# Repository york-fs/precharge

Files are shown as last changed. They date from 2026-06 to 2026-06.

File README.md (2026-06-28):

# Precharge Board







The precharge board is responsible for precharging the inverter's large capacitance through a dedicated relay and
resistor before the AIRs close.

[Latest Release](https://github.com/york-fs/precharge/releases/latest)
[Interactive BOM](https://york-fs.github.io/precharge/ibom.html)

## Features

* **CAN Communication**
* **AIR Relay Control**
* **HV Sampling of Accumulator and TS sides**

Render Preview

## Cloning

A recursive clone must be used to download the `kicad-library` repository:

    git clone --recursive https://github.com/york-fs/precharge.git

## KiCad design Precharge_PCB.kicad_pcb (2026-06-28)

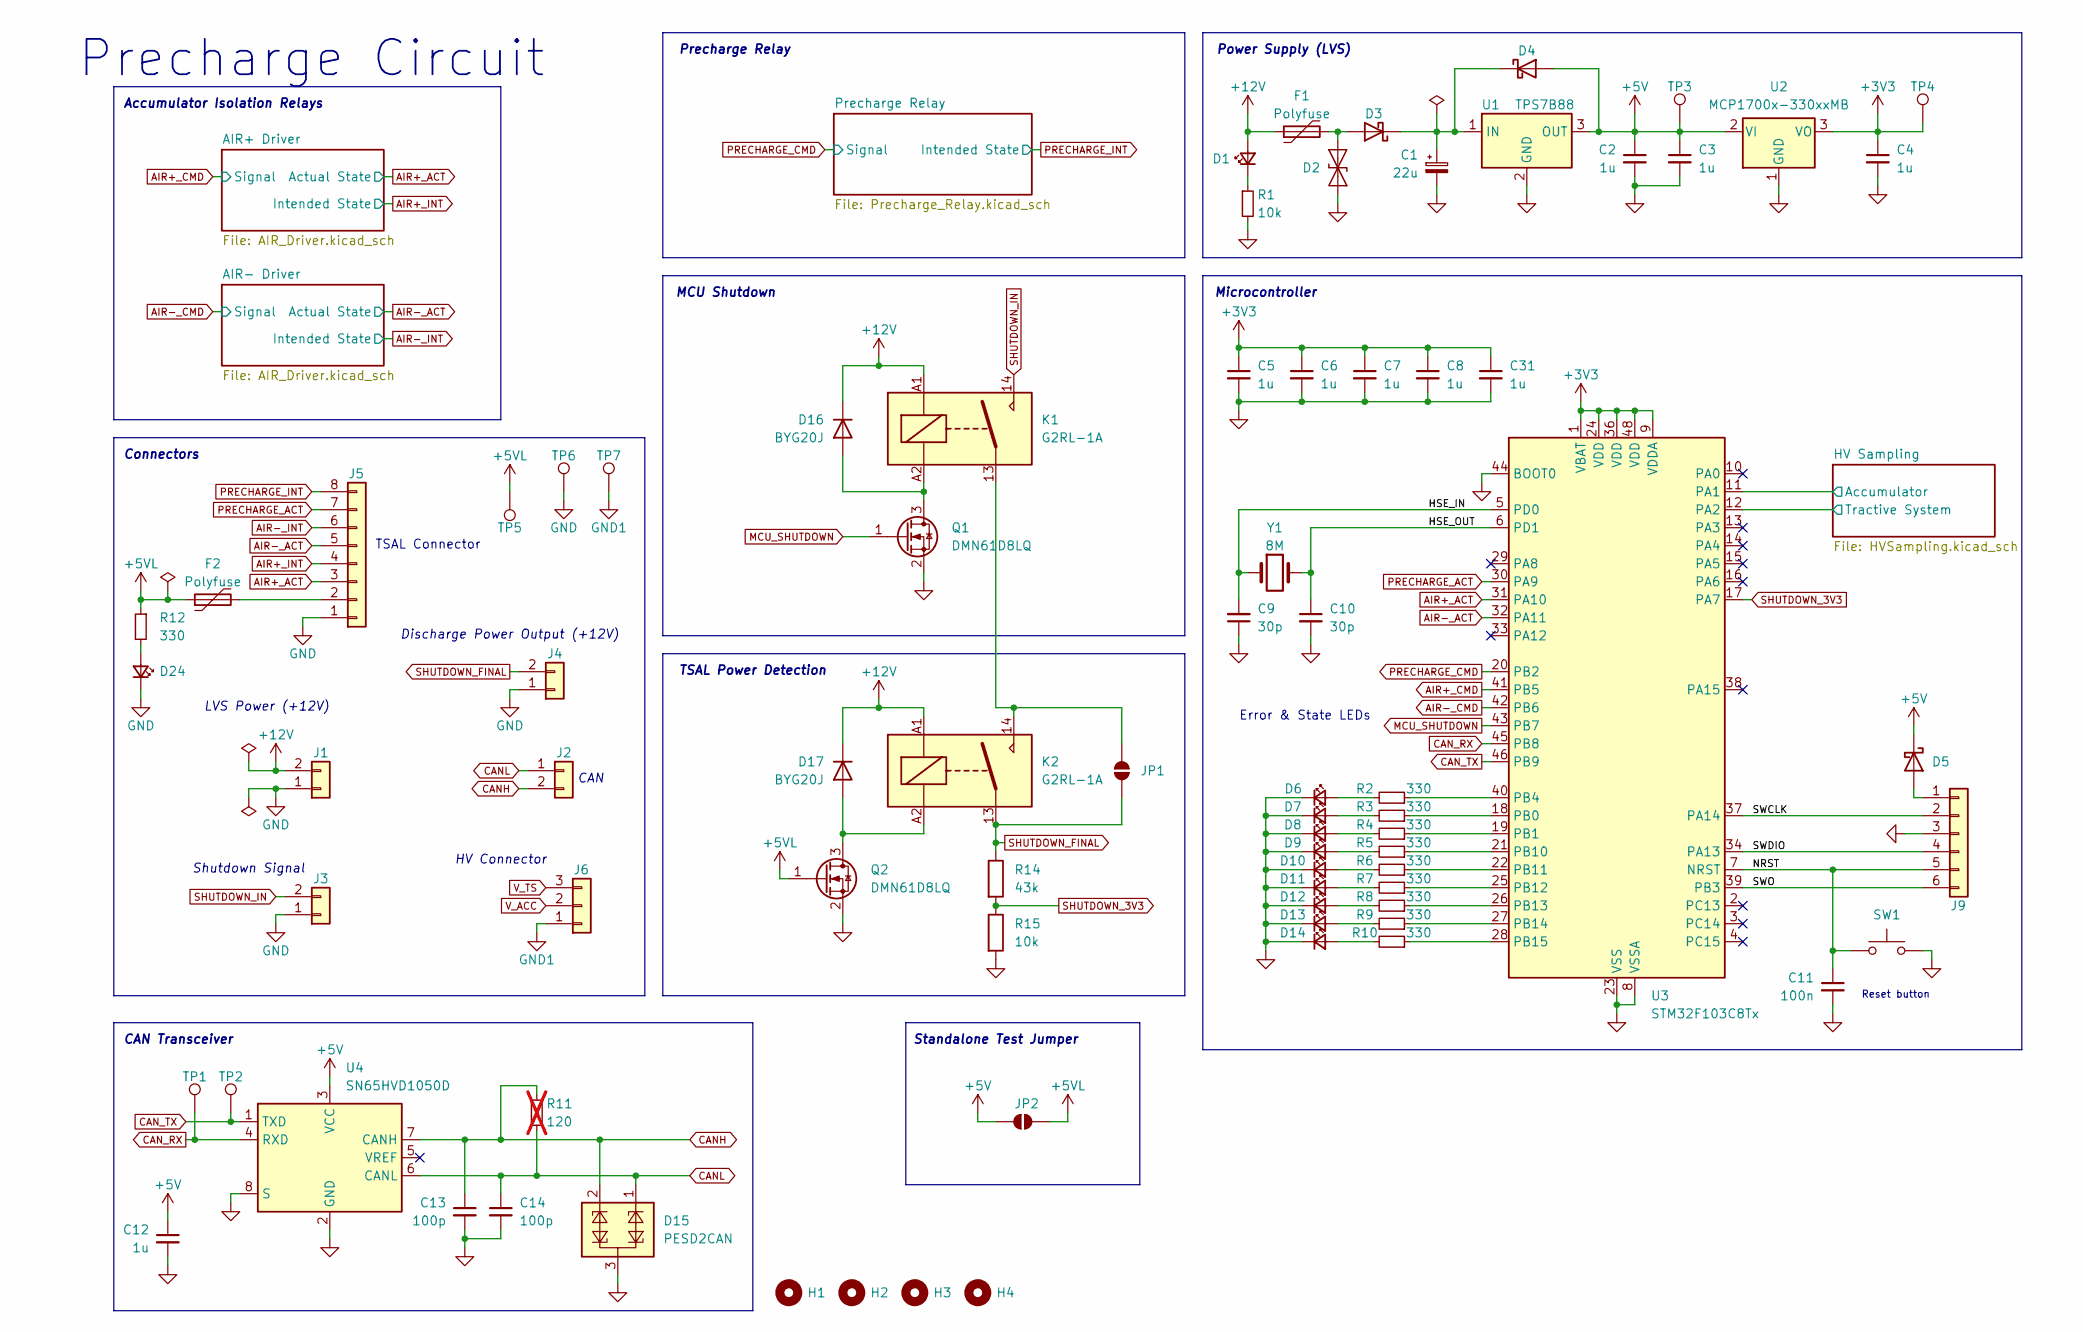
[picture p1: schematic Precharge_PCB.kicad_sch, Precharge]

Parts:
C1: 22u; CP_Elec_6.3x7.7; Mfr # EEEFK1J220XP; DigiKey # PCE3821CT-ND
C2, C3, C4, C5, C6, C7, C8, C12, C31: 1u; C_0603_1608Metric; Mfr # CL10B105KB8NQNC; LCSC # C5199872
C9, C10: 30p; C_0603_1608Metric; Mfr # GQM1875C2E300GB12D; DigiKey # 490-GQM1875C2E300GB12DCT-ND
C11: 100n; C_0603_1608Metric; Mfr # CL10B104KB8NNNC; DigiKey # 1276-1000-1-ND
C13, C14: 100p; C_0603_1608Metric; Mfr # GCM1885C2A101JA16D; DigiKey # 490-4771-1-ND
D1, D6, D7, D8, D9, D10, D11, D12, D13, D14, D24: LED_Small; LED_0603_1608Metric; Mfr # NCD0603R1; LCSC # C84263
D2: SMAJ24CA; D_SMA; Mfr # SMAJ24CA; DigiKey # SMAJ24CALFCT-ND
D3, D4, D5: D_Schottky; D_SOD-323; Mfr # NSR0530H; DigiKey # NSR0530HT1GOSCT-ND
D15: PESD2CAN; SOT-23; Mfr # PESD2CAN,215; DigiKey # 1727-3891-1-ND
D16, D17: BYG20J; D_SMA; Mfr # BYG20J-E3/TR; DigiKey # BYG20J-E3/TR3GICT-ND
F1, F2: Polyfuse; C_0805_2012Metric; Mfr # 0805L010/24YR; DigiKey # F11311CT-ND
H1, H2, H3, H4: MountingHole; MountingHole_3.2mm_M3
J1: Conn_01x02; MolexMicrofitPlus1x2; Mfr # 2157601022; DigiKey # 900-2157601022-ND
J2, J4: Conn_01x02; MolexMicrofitPlus1x2; Mfr # 2157601002; DigiKey # 900-2157601002-ND
J3: Conn_01x02; MolexMicrofitPlus1x2; Mfr # 2157601032; DigiKey # 900-2157601032-ND
J5: Conn_01x08; MolexMicrofitPlus1x8; Mfr # 2157601008; DigiKey # 900-2157601008-ND
J6: Conn_01x03; MolexMicrofitPlus1x3; Mfr # 2157601043; DigiKey # 900-2157601043-ND
J9: Conn_01x06; IDC-Connector-2x3; Mfr # HX JN1.27-2x3P ZZ H4.9; LCSC # C42372545
JP1, JP2: SolderJumper_2_Open; SolderJumper-2_P1.3mm_Open_TrianglePad1.0x1.5mm
K1, K2: G2RL-1A; Relay_SPST_Omron_G2RL-1A; Mfr # G2RL-1A-DC12; DigiKey # Z140-ND
Q1, Q2: DMN61D8LQ; SOT-23; Mfr # DMN61D8LQ-7; DigiKey # DMN61D8LQ-7DICT-ND
R1, R15: 10k; R_0603_1608Metric; Mfr # 0603WAF1002T5E; LCSC # C25804
R2, R3, R4, R5, R6, R7, R8, R9, R10, R12: 330; R_0603_1608Metric; Mfr # 0603WAF3300T5E; LCSC # C23138
R11: 120; R_0603_1608Metric; not fitted
R14: 43k; R_0603_1608Metric
SW1: SW_Push; SW_Push_1P1T_NO_Vertical_Wuerth_434133025816; Mfr # SKRPACE010; DigiKey # 4809-SKRPACE010CT-ND
TP1, TP2, TP3, TP4, TP5, TP6, TP7: TestPoint; TestPoint_Keystone_5000-5004_Miniature; Mouser # 534-5000; DigiKey # 36-5000-ND
U1: TPS7B88; TO-252-2; Mfr # TPS7B8850QKVURQ1; DigiKey # 296-TPS7B8850QKVURQ1CT-ND
U2: MCP1700x-330xxMB; SOT-89-3; Mfr # MCP1700T-3302E/MB; DigiKey # MCP1700T3302EMBCT-ND
U3: STM32F103C8Tx; LQFP-48_7x7mm_P0.5mm; Mfr # STM32F103C8T6; DigiKey # 497-17666-1-ND
U4: SN65HVD1050D; SOIC-8_3.9x4.9mm_P1.27mm; Mfr # SN65HVD1050DR; DigiKey # 296-26335-1-ND
Y1: 8M; Crystal_SMD_5032-2Pin_5.0x3.2mm; Mfr # X50328MSB2GI; LCSC # C115962

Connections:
+3V3: C4.1, C5.1, C6.1, C7.1, C8.1, C31.1, TP4.1, U2.3 (VO), U3.1 (VBAT), U3.9 (VDDA), U3.24 (VDD), U3.36 (VDD), U3.48 (VDD); also elsewhere on the board
+5V: C2.1, C3.1, C12.1, D4.2 (A), D5.1 (K), JP2.2 (B), TP3.1, U1.3 (OUT), U2.2 (VI), U4.3 (VCC)
+5VL: F2.1, JP2.1 (A), Q2.1 (G), R12.1, TP5.1; also elsewhere on the board
+12V: D1.2 (A), D16.1 (K), D17.1 (K), F1.1, J1.2, K1.A1, K2.A1
/HSE_IN: C9.2, U3.5 (PD0), Y1.1
/HSE_OUT: C10.1, U3.6 (PD1), Y1.2
/HV Sampling/Accumulator: U3.11 (PA1); also elsewhere on the board
/HV Sampling/Tractive System: U3.12 (PA2); also elsewhere on the board
/NRST: C11.1, J9.5, SW1.1, U3.7 (NRST)
/SWCLK: J9.2, U3.37 (PA14)
/SWDIO: J9.4, U3.34 (PA13)
/SWO: J9.6, U3.39 (PB3)
AIR+_ACT: J5.3, U3.31 (PA10); also elsewhere on the board
AIR+_CMD: U3.41 (PB5); also elsewhere on the board
AIR+_INT: J5.4; also elsewhere on the board
AIR-_ACT: J5.5, U3.32 (PA11); also elsewhere on the board
AIR-_CMD: U3.42 (PB6); also elsewhere on the board
AIR-_INT: J5.6; also elsewhere on the board
CANH: C13.1, D15.2 (C2), J2.2, R11.1, U4.7 (CANH)
CANL: C14.1, D15.1 (C1), J2.1, R11.2, U4.6 (CANL)
CAN_RX: TP1.1, U3.45 (PB8), U4.4 (RXD)
CAN_TX: TP2.1, U3.46 (PB9), U4.1 (TXD)
GND: C1.2, C2.2, C3.2, C4.2, C5.2, C6.2, C7.2, C8.2, C9.1, C10.2, C11.2, C12.2, C13.2, C14.2, C31.2, D2.1 (A1), D6.1 (K), D7.1 (K), D8.1 (K), D9.1 (K), D10.1 (K), D11.1 (K), D12.1 (K), D13.1 (K), D14.1 (K), D15.3 (CC), D24.1 (K), J1.1, J3.1, J4.1, J5.1, J9.3, Q1.2 (S), Q2.2 (S), R1.2, R15.2, SW1.2, TP6.1, U1.2 (GND), U2.1 (GND), U3.8 (VSSA), U3.23 (VSS), U3.35 (VSS), U3.44 (BOOT0), U3.47 (VSS), U4.2 (GND), U4.8 (S); also elsewhere on the board
GND1: J6.1, TP7.1; also elsewhere on the board
MCU_SHUTDOWN: Q1.1 (G), U3.43 (PB7)
unnamed: D1.1 (K), R1.1
unnamed: D2.2 (A2), D3.2 (A), F1.2
unnamed: C1.1, D3.1 (K), D4.1 (K), U1.1 (IN)
unnamed: D5.2 (A), J9.1
unnamed: D6.2 (A), R2.2
unnamed: D7.2 (A), R3.2
unnamed: D8.2 (A), R4.2
unnamed: D9.2 (A), R5.2
unnamed: D10.2 (A), R6.2
unnamed: D11.2 (A), R7.2
unnamed: D12.2 (A), R8.2
unnamed: D13.2 (A), R9.2
unnamed: D14.2 (A), R10.2
unnamed: D16.2 (A), K1.A2, Q1.3 (D)
unnamed: D17.2 (A), K2.A2, Q2.3 (D)
unnamed: D24.2 (A), R12.2
unnamed: F2.2, J5.2
unnamed: JP1.2 (B), K1.13, K2.14
unnamed: R3.1, U3.18 (PB0)
unnamed: R4.1, U3.19 (PB1)
unnamed: R2.1, U3.40 (PB4)
unnamed: R5.1, U3.21 (PB10)
unnamed: R6.1, U3.22 (PB11)
unnamed: R7.1, U3.25 (PB12)
unnamed: R8.1, U3.26 (PB13)
unnamed: R9.1, U3.27 (PB14)
unnamed: R10.1, U3.28 (PB15)
PRECHARGE_ACT: J5.7, U3.30 (PA9); also elsewhere on the board
PRECHARGE_CMD: U3.20 (PB2); also elsewhere on the board
PRECHARGE_INT: J5.8; also elsewhere on the board
SHUTDOWN_3V3: R14.2, R15.1, U3.17 (PA7)
SHUTDOWN_FINAL: J4.2, JP1.1 (A), K2.13, R14.1; also elsewhere on the board
SHUTDOWN_IN: J3.2, K1.14
V_ACC: J6.2; also elsewhere on the board
V_TS: J6.3; also elsewhere on the board

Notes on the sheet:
Microcontroller
Error & State LEDs
Connectors
Accumulator Isolation Relays
Standalone Test Jumper
TSAL Power Detection
CAN Transceiver
HV Connector
Power Supply (LVS)
Shutdown Signal
TSAL Connector
Precharge Relay
CAN
Discharge Power Output (+12V)
LVS Power (+12V)
Reset button
MCU Shutdown
Precharge Circuit

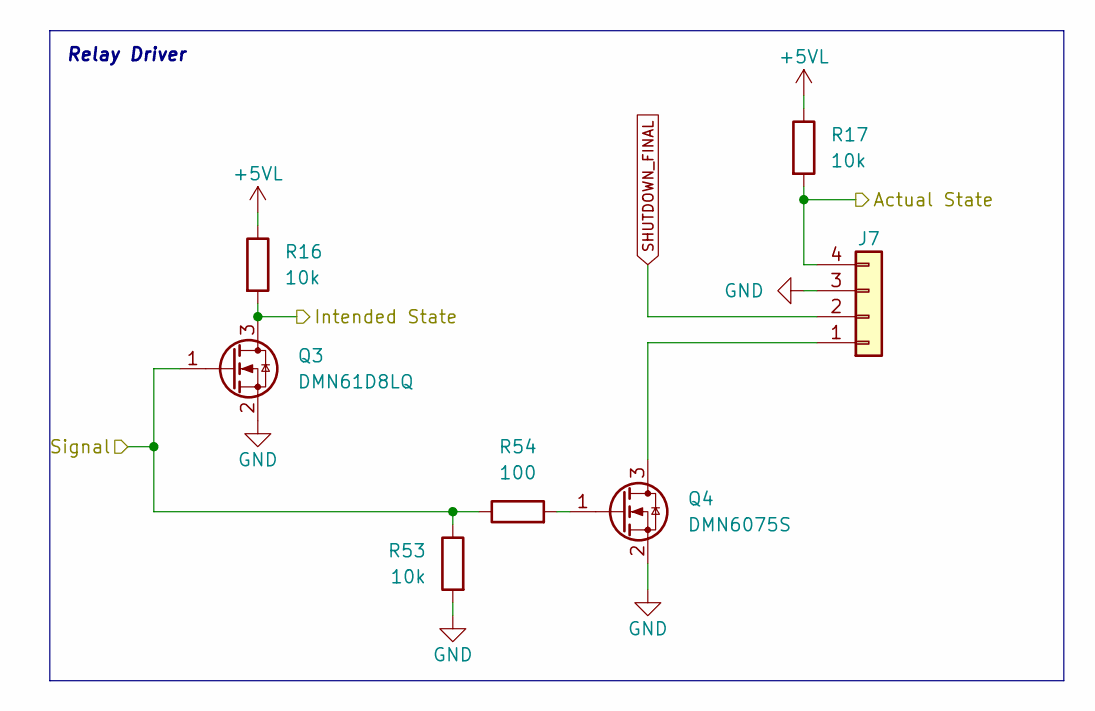
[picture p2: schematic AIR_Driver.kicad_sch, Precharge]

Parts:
J7: Conn_01x04; MolexMicrofitPlus1x4; Mfr # 2157601004; DigiKey # 900-2157601004-ND
Q3: DMN61D8LQ; SOT-23; Mfr # DMN61D8LQ-7; DigiKey # DMN61D8LQ-7DICT-ND
Q4: DMN6075S; SOT-23; Mfr # DMN6075S-7; DigiKey # DMN6075S-7DICT-ND
R16, R17, R53: 10k; R_0603_1608Metric; Mfr # 0603WAF1002T5E; LCSC # C25804
R54: 100; R_0603_1608Metric

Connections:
+5VL: R16.1, R17.1; also elsewhere on the board
AIR+_ACT: J7.4, R17.2; also elsewhere on the board
AIR+_CMD: Q3.1 (G), R53.1, R54.1; also elsewhere on the board
AIR+_INT: Q3.3 (D), R16.2; also elsewhere on the board
GND: J7.3, Q3.2 (S), Q4.2 (S), R53.2; also elsewhere on the board
unnamed: J7.1, Q4.3 (D)
unnamed: Q4.1 (G), R54.2
SHUTDOWN_FINAL: J7.2; also elsewhere on the board

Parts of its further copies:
J8: Conn_01x04; MolexMicrofitPlus1x4; Mfr # 2157601004; DigiKey # 900-2157601004-ND
Q5: DMN61D8LQ; SOT-23; Mfr # DMN61D8LQ-7; DigiKey # DMN61D8LQ-7DICT-ND
Q6: DMN6075S; SOT-23; Mfr # DMN6075S-7; DigiKey # DMN6075S-7DICT-ND
R18, R19, R55: 10k; R_0603_1608Metric; Mfr # 0603WAF1002T5E; LCSC # C25804
R56: 100; R_0603_1608Metric

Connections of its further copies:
+5VL: R18.1, R19.1; also elsewhere on the board
AIR-_ACT: J8.4, R19.2; also elsewhere on the board
AIR-_CMD: Q5.1 (G), R55.1, R56.1; also elsewhere on the board
AIR-_INT: Q5.3 (D), R18.2; also elsewhere on the board
GND: J8.3, Q5.2 (S), Q6.2 (S), R55.2; also elsewhere on the board
unnamed: J8.1, Q6.3 (D)
unnamed: Q6.1 (G), R56.2
SHUTDOWN_FINAL: J8.2; also elsewhere on the board

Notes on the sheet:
Relay Driver

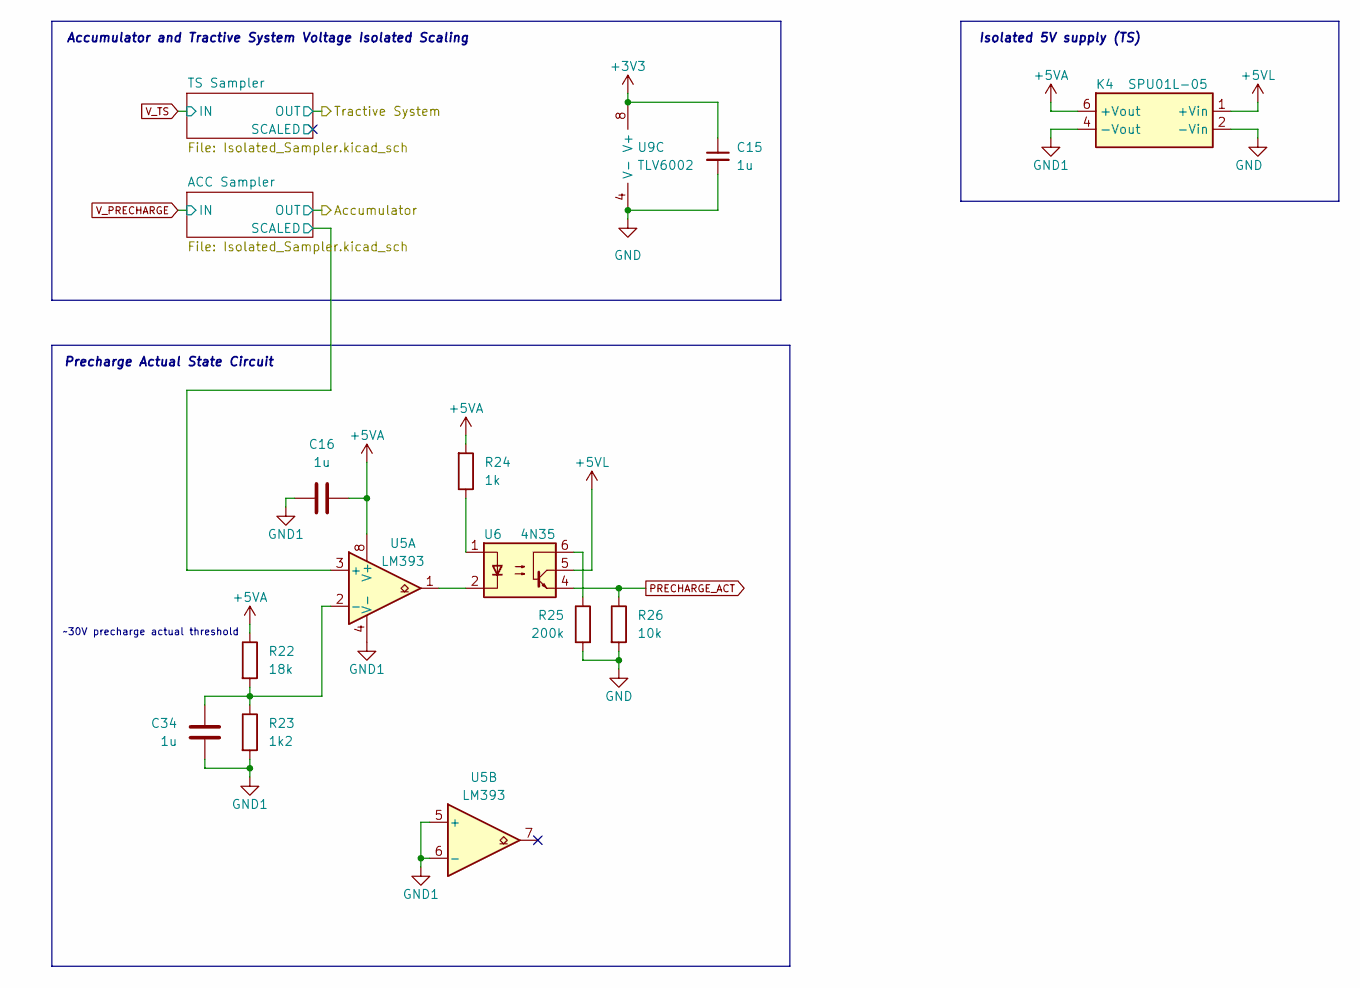
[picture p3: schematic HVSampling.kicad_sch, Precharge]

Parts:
C15, C16, C34: 1u; C_0603_1608Metric; Mfr # CL10B105KB8NQNC; LCSC # C5199872
K4: SPU01L-05; SPU01M-5; Mfr # SPU01L-05; DigiKey # 1866-4835-ND
R22: 18k; R_0603_1608Metric
R23: 1k2; R_0603_1608Metric
R24: 1k; R_0603_1608Metric; Mfr # 0603WAF1001T5E; LCSC # C21190
R25: 200k; R_0603_1608Metric
R26: 10k; R_0603_1608Metric; Mfr # 0603WAF1002T5E; LCSC # C25804
U5: LM393; SOIC-8_3.9x4.9mm_P1.27mm; Mfr # LM393DR; DigiKey # 296-1015-1-ND
U6: 4N35; DIP-6_W7.62mm; Mfr # 4N35M; DigiKey # 4N35MFS-ND
U9: TLV6002; SOIC-8_3.9x4.9mm_P1.27mm; Mfr # TLV6002QDRQ1; DigiKey # 296-TLV6002QDRQ1CT-ND

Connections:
+3V3: C15.1, U9.8 (V+); also elsewhere on the board
+5VA: C16.2, K4.6 (+Vout), R22.1, R24.2, U5.8 (V+); also elsewhere on the board
+5VL: K4.1 (+Vin), U6.5; also elsewhere on the board
/HV Sampling/ACC Sampler/SCALED: U5.3 (+); also elsewhere on the board
/HV Sampling/Tractive System: U9.7; also elsewhere on the board
GND: C15.2, K4.2 (-Vin), R25.2, R26.2, U9.4 (V-); also elsewhere on the board
GND1: C16.1, C34.1, K4.4 (-Vout), R23.2, U5.4 (V-), U5.5 (+), U5.6 (-); also elsewhere on the board
unnamed: R24.1, U6.1
unnamed: R25.1, U6.6
unnamed: U5.1, U6.2
unnamed: C34.2, R22.2, R23.1, U5.2 (-)
unnamed 84: U9.5 (+); also elsewhere on the board
unnamed 85: U9.6 (-); also elsewhere on the board
PRECHARGE_ACT: R26.1, U6.4; also elsewhere on the board

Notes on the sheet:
~30V precharge actual threshold
Precharge Actual State Circuit
Isolated 5V supply (TS)
Accumulator and Tractive System Voltage Isolated Scaling

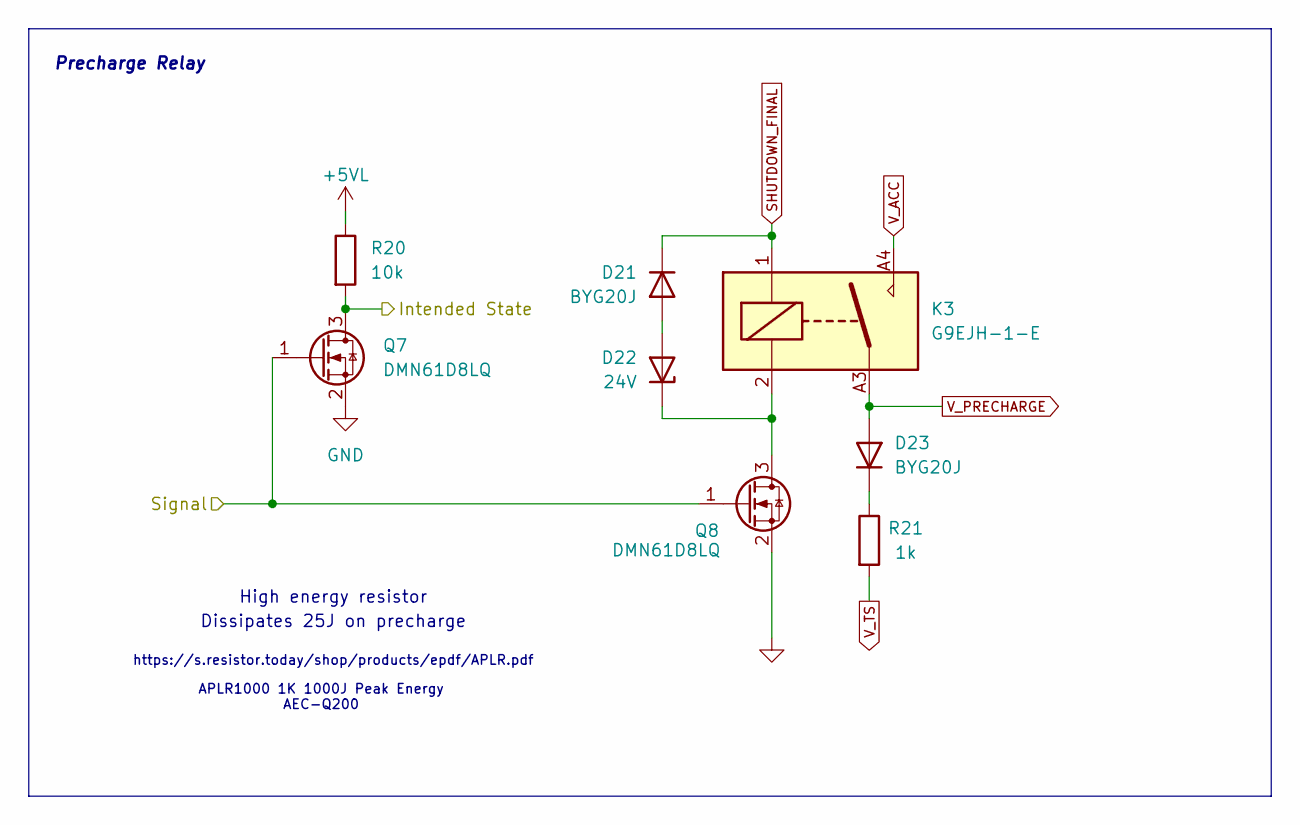
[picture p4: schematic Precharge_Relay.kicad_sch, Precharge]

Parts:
D21, D23: BYG20J; D_SMA; Mfr # BYG20J-E3/TR; DigiKey # BYG20J-E3/TR3GICT-ND
D22: 24V; D_SMA; Mfr # BZG05C24-M3-08; DigiKey # BZG05C24-M3-08GICT-ND
K3: G9EJH-1-E; Mfr # G9EJH-1-P-E DC12; DigiKey # 39-G9EJH-1-P-EDC12-ND
Q7, Q8: DMN61D8LQ; SOT-23; Mfr # DMN61D8LQ-7; DigiKey # DMN61D8LQ-7DICT-ND
R20: 10k; R_0603_1608Metric; Mfr # 0603WAF1002T5E; LCSC # C25804
R21: 1k; APLR1000; Mfr # APLR1000J1K00SE; DigiKey # 4506-APLR1000J1K00SE-ND

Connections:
+5VL: R20.1; also elsewhere on the board
GND: Q7.2 (S), Q8.2 (S); also elsewhere on the board
unnamed: D21.2 (A), D22.2 (A)
unnamed: D22.1 (K), K3.2, Q8.3 (D)
unnamed: D23.1 (K), R21.1
PRECHARGE_CMD: Q7.1 (G), Q8.1 (G); also elsewhere on the board
PRECHARGE_INT: Q7.3 (D), R20.2; also elsewhere on the board
SHUTDOWN_FINAL: D21.1 (K), K3.1; also elsewhere on the board
V_ACC: K3.A4, K3.B4; also elsewhere on the board
V_PRECHARGE: D23.2 (A), K3.A3, K3.B3; also elsewhere on the board
V_TS: R21.2; also elsewhere on the board

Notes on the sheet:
APLR1000 1K 1000J Peak Energy AEC-Q200
https://s.resistor.today/shop/products/epdf/APLR.pdf
Dissipates 25J on precharge
High energy resistor
Precharge Relay

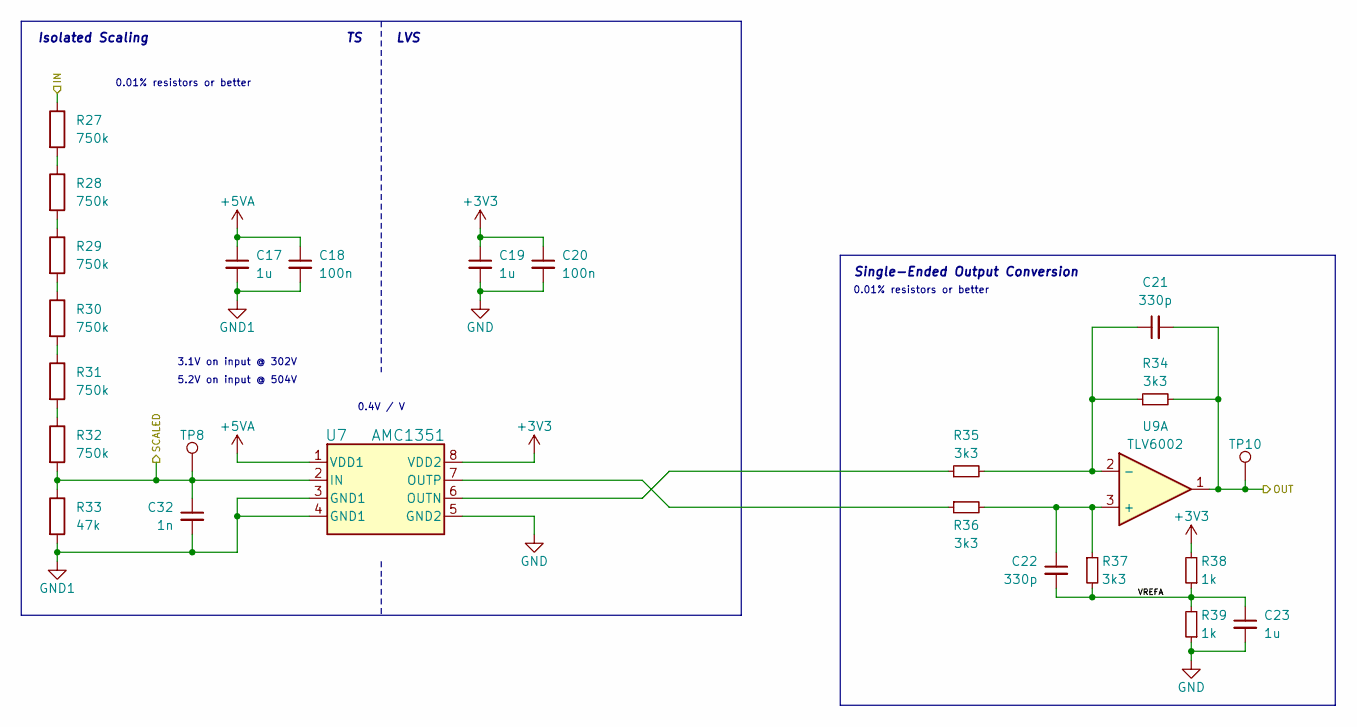
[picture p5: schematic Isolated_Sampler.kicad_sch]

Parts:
C17, C19, C23: 1u; C_0603_1608Metric; Mfr # CL10B105KB8NQNC; LCSC # C5199872
C18, C20: 100n; C_0603_1608Metric; Mfr # CL10B104KB8NNNC; DigiKey # 1276-1000-1-ND
C21, C22: 330p; C_0603_1608Metric; Mouser # 81-GCM1885C2A331J16D; DigiKey # 490-4948-1-ND
C32: 1n; C_0603_1608Metric; Mouser # 81-GRM39C102J50; DigiKey # 490-1451-1-ND
R27, R28, R29, R30, R31, R32: 750k; R_1206_3216Metric
R33: 47k; R_1206_3216Metric
R34, R35, R36, R37: 3k3; R_0603_1608Metric
R38, R39: 1k; R_0603_1608Metric; Mfr # 0603WAF1001T5E; LCSC # C21190
TP8, TP10: TestPoint; TestPoint_Keystone_5000-5004_Miniature; Mouser # 534-5000; DigiKey # 36-5000-ND
U7: AMC1351; SOIC-8_7.5x5.85mm_P1.27mm; Mfr # AMC1351QDWVRQ1; DigiKey # 296-AMC1351QDWVRQ1CT-ND
U9: TLV6002; SOIC-8_3.9x4.9mm_P1.27mm; Mfr # TLV6002QDRQ1; DigiKey # 296-TLV6002QDRQ1CT-ND

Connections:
+3V3: C19.1, C20.1, R38.2, U7.8 (VDD2); also elsewhere on the board
+5VA: C17.1, C18.1, U7.1 (VDD1); also elsewhere on the board
/HV Sampling/ACC Sampler/SCALED: C32.1, R32.2, R33.1, TP8.1, U7.2 (IN); also elsewhere on the board
/HV Sampling/ACC Sampler/VREFA: C22.2, C23.1, R37.2, R38.1, R39.2
/HV Sampling/Accumulator: C21.2, R34.2, TP10.1, U9.1; also elsewhere on the board
/HV Sampling/Tractive System: U9.7; also elsewhere on the board
GND: C19.2, C20.2, C23.2, R39.1, U7.5 (GND2); also elsewhere on the board
GND1: C17.2, C18.2, C32.2, R33.2, U7.3 (GND1), U7.4 (GND1); also elsewhere on the board
unnamed: R27.2, R28.1
unnamed: R28.2, R29.1
unnamed: R29.2, R30.1
unnamed: R30.2, R31.1
unnamed: R31.2, R32.1
unnamed: R35.1, U7.6 (OUTN)
unnamed: R36.1, U7.7 (OUTP)
unnamed: C22.1, R36.2, R37.1, U9.3 (+)
unnamed: C21.1, R34.1, R35.2, U9.2 (-)
unnamed 84: U9.5 (+); also elsewhere on the board
unnamed 85: U9.6 (-); also elsewhere on the board
V_PRECHARGE: R27.1; also elsewhere on the board

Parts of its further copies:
C24, C26, C30: 1u; C_0603_1608Metric; Mfr # CL10B105KB8NQNC; LCSC # C5199872
C25, C27: 100n; C_0603_1608Metric; Mfr # CL10B104KB8NNNC; DigiKey # 1276-1000-1-ND
C28, C29: 330p; C_0603_1608Metric; Mouser # 81-GCM1885C2A331J16D; DigiKey # 490-4948-1-ND
C33: 1n; C_0603_1608Metric; Mouser # 81-GRM39C102J50; DigiKey # 490-1451-1-ND
R40, R41, R42, R43, R44, R45: 750k; R_1206_3216Metric
R46: 47k; R_1206_3216Metric
R47, R48, R49, R50: 3k3; R_0603_1608Metric
R51, R52: 1k; R_0603_1608Metric; Mfr # 0603WAF1001T5E; LCSC # C21190
TP9, TP11: TestPoint; TestPoint_Keystone_5000-5004_Miniature; Mouser # 534-5000; DigiKey # 36-5000-ND
U8: AMC1351; SOIC-8_7.5x5.85mm_P1.27mm; Mfr # AMC1351QDWVRQ1; DigiKey # 296-AMC1351QDWVRQ1CT-ND

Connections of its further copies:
+3V3: C26.1, C27.1, R51.2, U8.8 (VDD2); also elsewhere on the board
+5VA: C24.1, C25.1, U8.1 (VDD1); also elsewhere on the board
/HV Sampling/TS Sampler/SCALED: C33.1, R45.2, R46.1, TP9.1, U8.2 (IN)
/HV Sampling/TS Sampler/VREFA: C29.2, C30.1, R50.2, R51.1, R52.2
/HV Sampling/Tractive System: C28.2, R47.2, TP11.1; also elsewhere on the board
GND: C26.2, C27.2, C30.2, R52.1, U8.5 (GND2); also elsewhere on the board
GND1: C24.2, C25.2, C33.2, R46.2, U8.3 (GND1), U8.4 (GND1); also elsewhere on the board
unnamed: R40.2, R41.1
unnamed: R41.2, R42.1
unnamed: R42.2, R43.1
unnamed: R43.2, R44.1
unnamed: R44.2, R45.1
unnamed: R48.1, U8.6 (OUTN)
unnamed: R49.1, U8.7 (OUTP)
unnamed 84: C29.1, R49.2, R50.1; also elsewhere on the board
unnamed 85: C28.1, R47.1, R48.2; also elsewhere on the board
V_TS: R40.1; also elsewhere on the board

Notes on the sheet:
3.1V on input @ 302V
0.01% resistors or better
Single-Ended Output Conversion
0.4V / V
5.2V on input @ 504V
Isolated Scaling
LVS

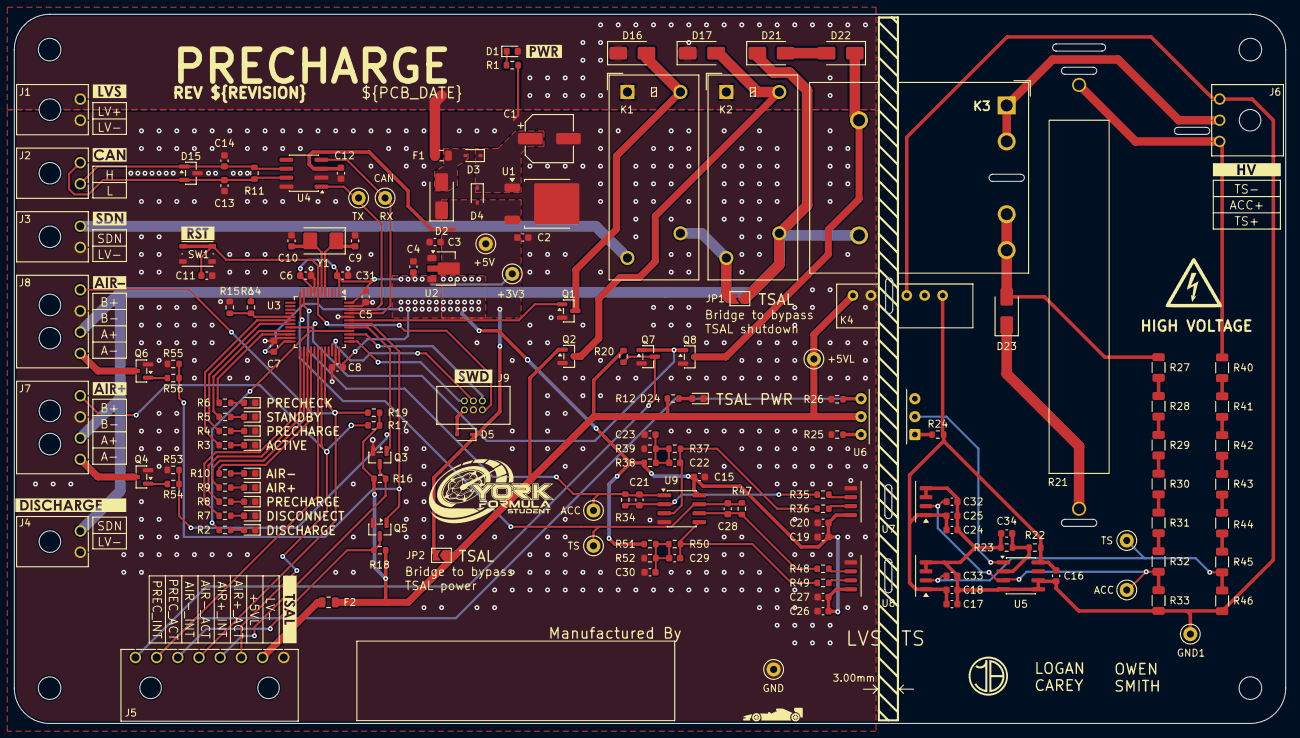
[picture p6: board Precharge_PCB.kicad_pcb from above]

Board: 2 copper layers, 180.0 x 100.4 mm, 172 parts (0 on the bottom side), 95 nets.

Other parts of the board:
kibuzzard-6910BB45: G***; kibuzzard-6910BB45
kibuzzard-6910BB76: G***; kibuzzard-6910BB76
kibuzzard-694056F2: G***; kibuzzard-694056F2
kibuzzard-694056F9: G***; kibuzzard-694056F9
kibuzzard-694058AC: G***; kibuzzard-694058AC
kibuzzard-694058D8: G***; kibuzzard-694058D8
kibuzzard-6940937D: G***; kibuzzard-6940937D
kibuzzard-69405726: G***; kibuzzard-69405726
kibuzzard-69405880: G***; kibuzzard-69405880
kibuzzard-69405918: G***; kibuzzard-69405918
kibuzzard-69408760: G***; kibuzzard-69408760

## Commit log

2025-11-19 pcb: Create blank PCB
    [Precharge_PCB.kicad_pcb]
2025-11-19 schematic: Remove unused EEPROM pins on MCU
    [Precharge_PCB.kicad_sch]
2025-11-19 schematic: Connect MCU shutdown pin
    [Precharge_PCB.kicad_sch]
2025-11-19 schematic: Change incorrect 3.3V net to 3V3
    [HVSampling.kicad_sch]
2025-11-19 schematic: Fix incorrect net on precharge relay
    [PrechargeRelayDriver.sch.kicad_sch]
2025-11-19 *: Add a variable for the revision
    [HVSampling.kicad_sch, PrechargeRelayDriver.sch.kicad_sch, Precharge_PCB.kicad_pcb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]
2025-11-19 schematic: Add a CAN connector
    [Precharge_PCB.kicad_sch]
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2025-12-09 Updated to single pole relay, removed relay drivers
    [HVSampling.kicad_sch, PrechargeRelayDriver.sch.kicad_sch, Precharge_PCB.kicad_sch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]
2025-12-13 schematic: Switch to NSR0530H from SS34
    [Precharge_PCB.kicad_sch]
2025-12-13 schematic: Switch to new push button
    [Precharge_PCB.kicad_sch]
2025-12-13 schematic: Switch to new IDC SWD header
    [Precharge_PCB.kicad_sch]
2025-12-13 schematic: Avoid using PA0 for analog sampling
    [Precharge_PCB.kicad_sch]
2025-12-13 schematic: Cleanup all global labels
    [HVSampling.kicad_sch, PrechargeRelayDriver.sch.kicad_sch, Precharge_PCB.kicad_sch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]
2025-12-13 schematic: Rename hierarchical sheets
    [AIR_Driver.kicad_sch, Precharge_PCB.kicad_sch, Precharge_Relay.kicad_sch]
2025-12-13 schematic: Remove old hierarchical sheets
    [IsolatedVoltageScaling.kicad_sch, Microcontroller.kicad_sch, PrechargeRelayDriver.sch.kicad_sch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]
2025-12-13 schematic: Update some symbols
    [AIR_Driver.kicad_sch, HVSampling.kicad_sch, Precharge_PCB.kicad_sch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]
2025-12-13 schematic: Do some general tidying
    [AIR_Driver.kicad_sch, Precharge_PCB.kicad_sch]
2025-12-13 schematic: Adjust MCU shutdown sampling divider ratio
    [Precharge_PCB.kicad_sch]
2025-12-13 schematic: Use SOD-323 zener diode
    [Precharge_PCB.kicad_sch]
2025-12-13 schematic: Fix unconnected wires
    [Precharge_PCB.kicad_sch]
2025-12-13 schematic: Add a pull-down to the TSAL power detection MOSFET
    [Precharge_PCB.kicad_sch]
2025-12-13 schematic: Mark AIR flyback diodes as DNP
    The contactors should have them built-in.
    [AIR_Driver.kicad_sch]
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2025-12-13 schematic: Update molex connectors
    [AIR_Driver.kicad_sch, Precharge_PCB.kicad_sch]
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2025-12-13 *: Use kicad-library exclusively
    [HVSampling.kicad_sch, Precharge_PCB.kicad_sch]
2025-12-13 schematic: Tie unused LM393 inputs low
    [HVSampling.kicad_sch]
2025-12-13 schematic: Connect relay actual states to the MCU
    [HVSampling.kicad_sch, Precharge_PCB.kicad_sch]
2025-12-13 schematic: Add a TVS diode to the LVS input
    [Precharge_PCB.kicad_sch]
2025-12-13 schematic: Create a hierarchical sheet for the isolated amplifiers
    [HVSampling.kicad_sch, Isolated_Sampler.kicad_sch]
2025-12-13 schematic: Add a 200k pull-down to the 4N35 base
    [HVSampling.kicad_sch]
2025-12-13 schematic: Renumber hierarchical pages
    [HVSampling.kicad_sch, Precharge_PCB.kicad_sch]
2025-12-13 schematic: Assign all footprints
    [HVSampling.kicad_sch, Isolated_Sampler.kicad_sch, Precharge_PCB.kicad_sch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]
2025-12-13 schematic: Power precharge relay from shutdown
    [Precharge_Relay.kicad_sch]
2025-12-13 schematic: Reassign reference designators
    [AIR_Driver.kicad_sch, HVSampling.kicad_sch, Isolated_Sampler.kicad_sch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]
2025-12-13 schematic: Fill out most of the BOM
    [AIR_Driver.kicad_sch, HVSampling.kicad_sch, Isolated_Sampler.kicad_sch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]
2025-12-14 pcb: Setup net classes and import components
    [AIR_Driver.kicad_sch, HVSampling.kicad_sch, Isolated_Sampler.kicad_sch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]
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2025-12-25 *: Remove unnecessary MOSFET pull-downs
    [Precharge_PCB.kicad_pcb, Precharge_PCB.kicad_sch]
2025-12-25 schematic: Add zener diode across precharge relay
    [Precharge_Relay.kicad_sch]
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2025-12-31 *: Add +5V to +5VL jumper
    This allows standalone precharge testing.
    [Precharge_PCB.kicad_pcb, Precharge_PCB.kicad_sch]
2025-12-31 pcb: Fix R21 designator orientation
    [Precharge_PCB.kicad_pcb]
2026-01-03 Added TSAL power bypass jumper
    [HVSampling.kicad_sch, Precharge_PCB.kicad_pcb, Precharge_PCB.kicad_sch]
2026-01-03 Increased thermal relief spoke thickness
    [Precharge_PCB.kicad_pcb]
2026-02-02 schematic: Fix BOM for SPU01L-05 DC-DC converter
    [HVSampling.kicad_sch, Precharge_PCB.kicad_pcb]
2026-02-02 schematic: Add BOM entries for precharge relay and associated zener
    [Precharge_PCB.kicad_pcb, Precharge_Relay.kicad_sch]
2026-02-03 *: Remove AIR flyback diodes
    [AIR_Driver.kicad_sch, Precharge_PCB.kicad_pcb, Precharge_PCB.kicad_sch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]
2026-02-03 schematic: Group all STM LEDs together
    [Precharge_PCB.kicad_pcb, Precharge_PCB.kicad_sch]
2026-02-03 *: Add test points around sampling
    [Isolated_Sampler.kicad_sch, Precharge_PCB.kicad_pcb, Precharge_PCB.kicad_sch]
2026-02-03 pcb: Update kicad library footprints
    [Precharge_PCB.kicad_pcb]
2026-02-04 *: Add filter capacitors on HV sense inputs
    [Isolated_Sampler.kicad_sch, Precharge_PCB.kicad_pcb]
2026-02-04 *: Change single-ended conversion bias resistors from 10k to 1k
    [Isolated_Sampler.kicad_sch, Precharge_PCB.kicad_pcb]
2026-02-04 *: Fix AMC1351 footprint
    [Isolated_Sampler.kicad_sch, Precharge_PCB.kicad_pcb]
2026-02-04 *: Set precharge comparator threshold resistors and add capacitor
    [HVSampling.kicad_sch, Precharge_PCB.kicad_pcb]
2026-04-17 schematic: Fix shutdown net direction on some labels
    [HVSampling.kicad_sch, Isolated_Sampler.kicad_sch, Precharge_PCB.kicad_sch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]
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2026-04-22 *: Bump revision and date for revision B
    [AIR_Driver.kicad_sch, HVSampling.kicad_sch, Isolated_Sampler.kicad_sch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]
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
